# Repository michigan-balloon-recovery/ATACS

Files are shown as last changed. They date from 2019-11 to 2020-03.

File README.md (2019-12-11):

# ATACS
*the* Aerial Termination And Communication System

A global-range, two-way communication system for high-altitude balloons that enables reliable telemetry beaconing and on-demand flight termination.

## Subdirectories
* [Hardware](./hardware/README.md)
* Software
    * [Ground Station](./software/groundstation/README.md)
    * [RTOS](./software/rtos/README.md)

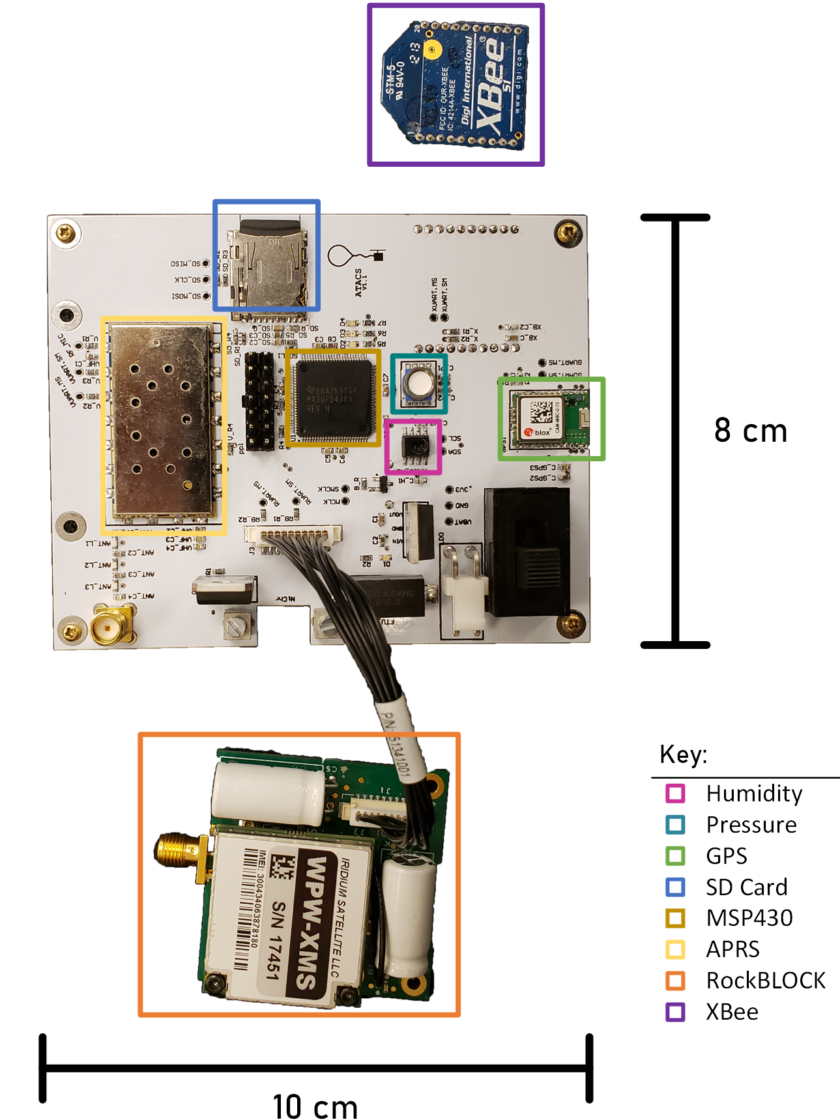
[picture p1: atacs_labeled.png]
Labeled PCB


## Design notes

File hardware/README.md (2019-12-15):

# ATACS hardware
Only tested in Altium 17, but should work in any version >=17. 

Simply open `board/ATACS.PrjPcb` in Altium and enjoy!

[Order a populated board on CircuitHub](https://circuithub.com/projects/MBuRST/ATACS/revisions/24389)

## Board Preview
**Top**

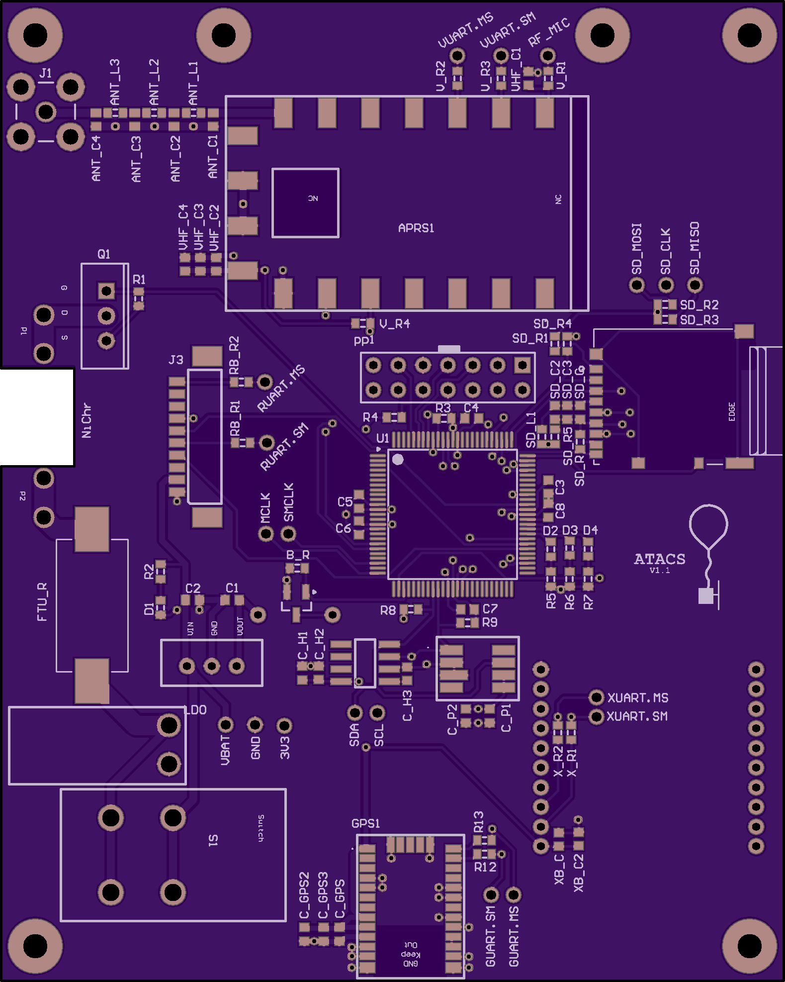
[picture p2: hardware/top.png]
Top


**Bottom**

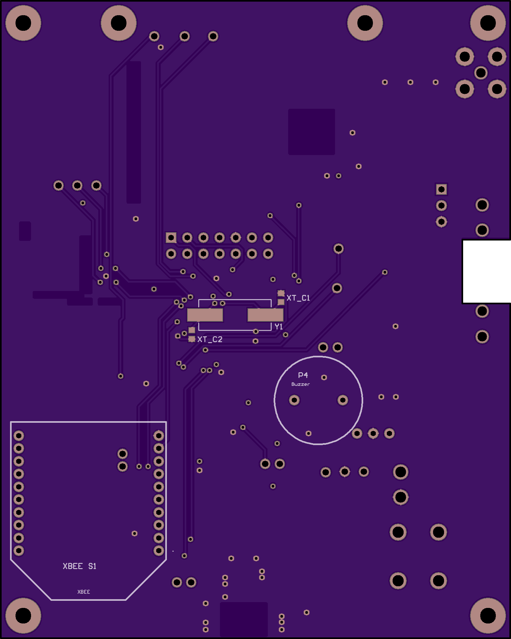
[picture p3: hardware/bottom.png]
Bottom


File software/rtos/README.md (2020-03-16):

# ATACS software
## Import instructions for Code Composer Studio 9
1. After installing CCS9, configure it to use a workspace that is **not** the same as the project directory.
2. `File` > `Import` > `Code Composer Studio` > `CCS Projects`
3. Set import source as `ATACS/software/rtos`, then Finish.

`rtos` should now appear in the Project Explorer pane

## Driver documentation
1. [APRS](./src/aprs/README.md)
2. [Buzzer](./src/buzzer/README.md)
3. [GNSS](./src/gnss/README.md)
4. [I2C](./src/I2C/README.md)
5. [Logging](./src/logging/README.md)
6. [Ring Buffer](./src/ring_buff/README.md)
7. [RockBLOCK](./src/RockBLOCK/README.md)
8. [Sensors](./src/Sensors/README.md)
9. [UART](./src/uart/README.md)
10. [XBee](./src/XBee/README.md)

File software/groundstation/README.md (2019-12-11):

# ATACS Ground Station software
## Dependencies
1. Windows Operating System
2. Python3 Installed
3. Firefox browser installed
4. Gmail account without duo authentication (RockBLOCK messages must be routed to this address on their control panel)
5. RockBLOCK account with credits available (to send messages)
6. Google Maps API key

## Usage
1. Download `groundstation.py`. Place it into a folder, it will generate a few files while running. Open the script in a text editor, we will have to change a few lines of the software.
2. Fill in your RockBLOCK username, password, and imei inside of the `rb_send_message()` function in the Python code.
3. Fill in your Google Maps API key inside of the `process_rb_message()` function in the Python code.
4. Make sure Firefox is installed and added to your enviornmental variables. This isn't difficult to do, try looking up how to do this for your operating system.
5. Open `groundstation.py` from terminal. Enter your email username and password. This must be the email that has RockBLOCK data being routed to it.
6. Press 'g' to get and decode the most recent packet from the RockBLOCK.
7. Press 's' to send a message to the RockBLOCK. Press 'f' afterward to cut the FTU. Sending commands to other payloads via 'p' is not yet implemented.
8. After 'q' to quit the program.
9. The program will loop forever until you quit.

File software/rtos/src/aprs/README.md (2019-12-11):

# APRS driver
[APRS (Automatic Packet Reporting System)](https://en.wikipedia.org/wiki/Automatic_Packet_Reporting_System) driver which uses Timer A1 to produce a PWM signal which, after being low-pass filtered, emulates the [AFSK](https://en.wikipedia.org/wiki/Frequency-shift_keying) tones expected by APRS. 

## Library Dependencies
1. FreeRTOS (semaphore and mutex support)
2. [Gustavo Litovsky's UART driver for MSP430](../uart/README.md) (modified to use [Frame-preserving ring buffer](../ring_buff/README.md))
3. [ATACS RockBLOCK](../RockBLOCK/README.md)
4. [ATACS GNSS](../gnss/README.md)
5. [ATACS Sensors](../Sensors/README.md)

## Hardware resources
* USCI A3
   * RX pin: P10.5
   * TT pin: P10.4

* Timer A1
   * CCR1 Output (TX): P2.2

* GPIO Pins
    * DRA818V PD pin:  P1.2
    * DRA818V PTT pin: P1.3

## Usage
* In `aprs.h`
    1. Set APRS source and destination callsigns. For most users, destination should remain as `APRS` and source should be the licensed operator's callsign.
    2. Set APRS comment (optional)
    3. Set APRS transmit period (should not be lower than `60000`)
    4. Set GPIO pins used by the RF module for PD (on/off) and PTT (push-to-talk, transmit enable)
    5. Set APRS transmit active level (active low or high)
* **ADVANCED USERS:** If you would like to modify beacon behavior, see the definition of `task_aprs` and `aprs_beacon` in `aprs.c`

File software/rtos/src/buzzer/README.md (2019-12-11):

# Buzzer Driver
Buzzer driver for:
1. Controlling when a buzzer is on or off. 

## Library Dependencies
1. FreeRTOS (timing support)

## Hardware Resources
1. GPIO Pin
   1. Buzzer Control Pin: P2.3

## Usage
1. Register `task_buzzer()` with the FreeRTOS kernel (ex. `xTaskCreate(task_buzzer, "buzzer", 128, NULL, 1, NULL);`).
2. Set the time the buzzer spends on in milliseconds by editing the `#define` in `buzzer.h` (ex. `#define BUZZ_ON_MS 1000`).
3. Set the timer the buzzer spends off in milliseconds by editing the `#define` in `buzzer.h` (ex. `#define BUZZ_OFF_MS 30000`).

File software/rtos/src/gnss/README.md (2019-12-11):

# GNSS Driver
GNSS (Global Navigation Satellite System) driver for:
1. generic modules through NMEA (`./NMEA.c`)
2. UBlox modules through UBX (not yet implemented)

## Library Dependencies
1. [FreeRTOS](https://www.freertos.org/index.html) (semaphore and mutex support)
2. [Gustavo Litovsky's UART driver for MSP430](../uart/README.md) (modified to use [Frame-preserving ring buffer](../ring_buff/README.md))

## Hardware Resources
1. USCI A0
   1. Tx pin: P3.4
   2. Rx pin: P3.5

## Usage
1. select between NMEA and UBX using the macro in `./GNSS.h` (i.e. `#define GNSS_NMEA` or `#define GNSS_UBX`)
2. set buffer lengths to desired sizes in `./GNSS.h`
3. add extra message decoders and get functions to `./NMEA.c` or `./UBX.c` if more data is necessary (such as expected error)
4. register `task_gnss()` with the FreeRTOS kernel (ex. `xTaskCreate(task_gnss, "gnss", 128, NULL, 1, NULL);`)
5. use get functions (`gnss_get_time()`, `gnss_get_location()`, `gnss_get_altitude()`, etc.) to retrieve GNSS data
6. use interrupt functions (`gnss_disable_interrupts()`, `gnss_enable_interrupts()`) to allow critical sections in other regions of code

## Adding NMEA Decoders
The NMEA decoding framework is designed to allow modular additions of sentence decoders depending on application. 
Refer to the NMEA spec or your GNSS module's datasheet to decide which sentences to decode.
1. **Add field decoder functions as necessary**: All NMEA sentences are encoded in ASCII so functions must be written to convert each field to a binary representation depending on what the contents of the field is. The function must follow this prototype: `static bool gnss_nmea_field_custom(uint8_t *start, uint8_t *end, void *data)` where `start` is a pointer to the beginning of the field and `end` is a pointer to the end of the field. `data` is a void pointer that can be used to return the decoded data.
2. **Add field decoder prototype**: add the function prototype for the field decoder in the *private prototypes* section at the top of `./NMEA.c`.
3. **decode all desired fields in the desired sentence case**: `gnss_nmea_decode_standard_msg()` and `gnss_nmea_decode_PUBX()` contain switch cases to sort the decoded sentences by ID. Add `gnss_nmea_decode_field()` calls with a function pointer to your custom field decoder to decode any desired fields in the case of the sentence you want to decode. The *GGA* example can be used as reference.
4. **store any new data in the GNSS global struct**: modify `./GNSS.h` to include your new data in the `gnss_t` type.
5. **implement get functions for any new data made available**: add custom get functions to `./GNSS.c` to retreive your new data. Ensure checks are made that the global struct has been initialized and the data mutex is available (ex. `gnss_obj->is_valid && xSemaphoreTake(gnss_obj->data_mutex, 100) == pdFALSE`).

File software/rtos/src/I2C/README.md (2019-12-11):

# I2C Driver
I2C (Inter-Integrated Circuits) driver for:
1. Sending messages from a microcontroller to I2C devices
2. Retrieving messages from I2C devices 

## Library Dependencies
1. [FreeRTOS](https://www.freertos.org/index.html) (semaphore and mutex support)

## Hardware Resources
1. USCI B0
   1. SDA: P3.1
   2. SCL: P3.2

## Usage
1. Set buffer lengths to desired sizes in i2c_driver.c
2. Use i2c_setup() to initialize I2C communication on UCB0
3. Use i2c_write() to send data from the microprocessor to an I2C device. 
4. Use i2c_read() to tell the microporccesor retrieve data from an I2C device. 
5. Use interrupt functions (i2c_enable_interrupts(), i2c_disable_interrupts()) to allow critical sections in other regions of code.

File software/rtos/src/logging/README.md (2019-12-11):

# Logging
Task for periodic logging and API for custom, event based logging.

## Library Dependencies
1. [FreeRTOS](https://www.freertos.org/index.html) (semaphore and mutex support)
2. [FatFs](http://elm-chan.org/fsw/ff/00index_e.html) fat32 file system
3. SPI driver from [Texas Instruments MSP430 MMC driver](http://www.ti.com/lit/an/slaa281c/slaa281c.pdf)

## Hardware Resources
1. USCI B3
   1. CS: P10.0
   2. SIMO: P10.1
   3. SOMI: P10.2
   4. CLK: P10.3
   
## Usage: Periodic Logging
1. Configure logging file sizes, period, etc in `./logging.h` **NOTE:** the most recent log will be unreadable if the logging is interrupted (device turned off, SD card removed) while writing. Size your logs small enough to avoid this.
2. Modify `log_init()` to start any custom logging sessions or change log file names/paths
3. Add any custom logging sessions to the `task_log()` function
   1. Call `log_resume_session()` before writing to the SD card
   2. Check that `log_resume_session()` returns true before writing anything to the file. This prevents two tasks from writing to the file at the same time and ensure the file is opened correctly.
   3. Write to the SD card using the file pointer returned by `log_resume_session()`
   4. Call `log_pause_session()` after the current entry has been written to the SD card
3. Register `task_log()` with the FreeRTOS kernel (ex. `xTaskCreate(task_log, "Logging", 512, NULL, 1, NULL);`)

## Usage: Event Based Logging
1. Configure logging file sizes, period, etc in `./logging.h` **NOTE:** the most recent log will be unreadable if the logging is interrupted (device turned off, SD card removed) while writing. Size your logs small enough to avoid this.
2. Modify `log_init()` to start any custom logging sessions or change log file names/paths
3. Create custom logging functions (ex. `log_gnss()`) for every device to log
   1. Call `log_resume_session()` before writing to the SD card
   2. Check that `log_resume_session()` returns true before writing anything to the file. This prevents two tasks from writing to the file at the same time and ensure the file is opened correctly.
   3. Write to the SD card using the file pointer returned by `log_resume_session()`
   4. Call `log_pause_session()` after the current entry has been written to the SD card
4. Call custom logging functions from any other FreeRTOS task. Logs are not synchronized with this method, so ensure to same timestamps or other contextual info.

## Log Format
The logging driver can theoretically be used to write in any format, but by default logs in Comma Seperated Value (CSV) format which can be read using Excel or Matlab.
Every file is writen with a custom header specified when the logging session is created with `log_start_session()`.
The logging driver will then allow `LOG_MAX_ENTRIES` to be written to a log file before incrementing the file name. 
The initial file name is specified when calling `log_start_session()` and must end in a numeric sequence with enough leading zeros to prevent increasing the string length.

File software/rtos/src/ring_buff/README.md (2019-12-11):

# Frame-preserving Ring Buffer
Ring buffer designed to prevent fragmented frames by independently storing byte and frame position.

## Library Dependencies
None

## Hardware Resources
None

## Usage
## Initialization
1. Create a global-scope array of type `uint8_t` or equivalent
2. Call `ring_buff_init()` and pass in a empty `ring_buff_t` instance and the byte array to use.

## Write to Buffer
1. Call `ring_buff_write_clear_packet()` at the beginning of a frame to clear out any partial frames
2. Call `ring_buff_write()` to add each byte of the frame
3. Call `ring_buff_write_finish_packet()` to mark the packet as finished. **Warning:** If the frame isn't marked as finished, it will be deleted when `ring_buff_write_clear_packet()` is called.

## Read from Buffer
1. Call `ring_buff_read_clear_packet()` at the beginning of a read to ensure the pointer is at the start of a frame
2. Call `ring_buff_read()` to read in each byte of the frame
3. Call `ring_buff_read_finish_packet()` when the End-Of-Frame (EOF) is detected to mark the frame as read. **Warning:** If the frame isn't marked as finished, the buffer will be unable to use the memory occupied by the current frame.

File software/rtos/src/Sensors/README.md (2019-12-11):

# Sensor Driver
Sensor driver for:
1. Calculating and retrieving pressure, humidity, and temperature data

## Library Dependencies
1. [FreeRTOS](https://www.freertos.org/index.html) (semaphore and mutex support)
2. [i2c driver](../I2C/README.md) 

## Hardware Resources
1. USCI B0
   1. SDA pin: P3.1
   2. SCL pin: P3.2

## Usage
1. Register task_humidity and task_pressure with the FreeRTOS kernel.
   (ex. `xTaskCreate(task_pressure, "pressure", 1024,NULL,1,NULL);`)
2. Use `sens_init_pressure()` to initialize the pressure sensor and read in its calibration values. 
   There is no initialization necessary for the humidity sensor.
3. Use `sens_calc_pressure()` to initialize a new pressure and temperature reading from the pressure sensor.
4. Use `sens_calc_humidity()` to initialize a new humidity and temperature reading from the humidity sensor.
5. Use `sens_get_pres()` to retrieve the current pressure reading.
6. Use `sens_get_ptemp()` to retrieve the current temperature reading from the pressure sensor.
7. Use `sens_get_humid()` to retrieve the current humidity reading.
8. Use `sens_get_htemp()` to retriece the current temperature reading from the humidity sensor.
9. Use functions (`sens_disable_interrupts()`, `sens_enable_interrupts()`) to safely allow for critical sections in other regions of code.

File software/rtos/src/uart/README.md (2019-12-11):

# UART Driver
Genaric UART driver for the MSP430 by Gustavo Litovsky (Refer to copywrite notice in `./uart.c`).
Has been heavily modified to support Paul Young's [Frame-preserving ring buffer](../ring_buff/README.md) as well as adding callback functions for RX and TX operations.

## Library Dependencies
1. Gustavo Litovsky's [original MSP430 UART driver](https://github.com/glitovsky38412/msp430uartdriver)
2. Paul Young's [Frame-preserving ring buffer](../ring_buff/README.md)

## Hardware Resources
configured by application drivers

## Usage

## Initialization
1. Create and initialize a `UARTConfig` struct, filling in *moduleName*, *PortNum*, *RxPinNum*, *TxPinNum*, *clkRate*, *baudRate*, *clkSrc*, *databits*, *parity*, and *stopbits* based on the application
2. Call `initUSCIUart()`, passing in the `UARTConfig` struct and any ring buffers being used. If a ring buffer isn't being used due to callback functions, a NULL pointer can be passed in instead.
3. Call `initUartRxCallback()` and/or `initUartTxCallback()` to initialize callback functions
   1. A function pointer to a callback of prototype `void callback_fcn(void *param, uint8_t datum)` should be passed in
   2. data can be returned from the callback function using the void pointer *params* that will be passed into the callback function

## RX
After initialization, the RX interrupt is automatically enabled. When the interrupt is triggered, the callback function will be called, if initialized. 
If no callback is defined, the interrupt will load the byte into the ring buffer and finish the frame.
If no callback or ring buffer is defined, nothing will happen.

## TX: Blocking
A byte array can be transmitted over UART without interrupts by using `uartSendDataBlocking()`. This will lock up the current task until the transmission is completed.
No callbacks or internal buffers are used for this transmission method.

## TX: Interrupts
Interrupts can be used to free the task for other operations while transmission is occuring. The driver supports callback functions and a Frame-preserving ring buffer.
1. Start the transmission using `uartSendDataInt()`. This enables TX interrupts and triggers the first interrupt with software.
2. After each byte is transmitted, an interrupt is triggered which calls the callback function, if defined.
3. If no callback function is defined, a single byte is read from the ring buffer (and transmitted) and the frame is marked as complete.
4. If no callback or ring buffer is defined, nothing will happen

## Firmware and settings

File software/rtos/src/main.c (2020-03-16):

/* Standard includes. */
#include <MSP430-5438STK_HAL/hal_MSP430-5438STK.h>
#include <stdio.h>
/* FreeRTOS includes. */
#include "FreeRTOS.h"
#include "task.h"
#include "semphr.h"

/* Hardware includes. */
#include "driverlib.h"
#include "uart.h"
#include "gnss.h"
#include "aprs.h"
#include "rockblock.h"
#include "sensors.h"
#include "i2c_driver.h"
#include "logging.h"
#include "buzzer.h"

/*-----------------------------------------------------------*/

static void prvSetupHardware(void);

/*-----------------------------------------------------------*/

void main( void ) {
    /* Initialize Hardware */
    prvSetupHardware();

    /* Create Tasks */
    xTaskCreate((TaskFunction_t) task_gnss,           "gnss",             128, NULL, 1, NULL);
    xTaskCreate((TaskFunction_t) task_aprs,           "aprs",             512, NULL, 1, NULL);
    xTaskCreate((TaskFunction_t) task_pressure,       "pressure",         128, NULL, 1, NULL);
    xTaskCreate((TaskFunction_t) task_humidity,       "humidity",         128, NULL, 1, NULL);
    xTaskCreate((TaskFunction_t) task_buzzer,         "buzzer",           128, NULL, 1, NULL);
    xTaskCreate((TaskFunction_t) task_rockblock,      "RockBLOCK",        512, NULL, 1, NULL);
    xTaskCreate((TaskFunction_t) task_log,            "Logging",          512, NULL, 1, NULL);


    /* Start the scheduler. */
    __bis_SR_register(GIE); // Global interrupt enable
    vTaskStartScheduler();

    /* If all is well then this line will never be reached.  If it is reached
    then it is likely that there was insufficient (FreeRTOS) heap memory space
    to create the idle task.  This may have been trapped by the malloc() failed
    hook function, if one is configured. */
    for( ;; );
}

/*-----------------------------------------------------------*/

static void prvSetupHardware(void) {
	taskDISABLE_INTERRUPTS();
	
	/* Disable the watchdog. */
	WDTCTL = WDTPW + WDTHOLD;

	/* Set DCO to 16MHz, uses configCPU_CLOCK_HZ, but PMM_CORE_LEVEL_x is hardcoded */
	GPIO_setAsPeripheralModuleFunctionOutputPin(GPIO_PORT_P1, GPIO_PIN6);
	GPIO_setAsPeripheralModuleFunctionOutputPin(GPIO_PORT_P2, GPIO_PIN0);

	//Set VCore = 2 for 16MHz clock
    PMM_setVCore(PMM_CORE_LEVEL_2);

    //Set DCO FLL reference = REFO
    UCS_initClockSignal(
        UCS_FLLREF,
        UCS_REFOCLK_SELECT,
        UCS_CLOCK_DIVIDER_1
        );

    UCS_initFLLSettle(
            configCPU_CLOCK_HZ / 1000,
            configCPU_CLOCK_HZ / 32768
    );

    halBoardInit();

    /* debug LEDs */
    GPIO_setAsOutputPin(GPIO_PORT_P8, GPIO_PIN2);
    GPIO_setAsOutputPin(GPIO_PORT_P8, GPIO_PIN3);
    GPIO_setAsOutputPin(GPIO_PORT_P8, GPIO_PIN4);
    GPIO_setOutputLowOnPin(GPIO_PORT_P8, GPIO_PIN2);
    GPIO_setOutputLowOnPin(GPIO_PORT_P8, GPIO_PIN3);
    GPIO_setOutputLowOnPin(GPIO_PORT_P8, GPIO_PIN4);

    /* UART */
    initUartDriver();

    /* I2C */
    i2c_setup();


}
/*-----------------------------------------------------------*/


void vApplicationTickHook(void) {
	return;
}

/*-----------------------------------------------------------*/

/* The MSP430X port uses this callback function to configure its tick interrupt.
This allows the application to choose the tick interrupt source.
configTICK_VECTOR must also be set in FreeRTOSConfig.h to the correct
interrupt vector for the chosen tick interrupt source.  This implementation of
vApplicationSetupTimerInterrupt() generates the tick from timer A0, so in this
case configTICK_VECTOR is set to TIMER0_A0_VECTOR. */
void vApplicationSetupTimerInterrupt(void) {
    const unsigned short usACLK_Frequency_Hz = 32768;

	/* Ensure the timer is stopped. */
	TA0CTL = 0;

	/* Run the timer from the ACLK. */
	TA0CTL = TASSEL_1;

	/* Clear everything to start with. */
	TA0CTL |= TACLR;

	/* Set the compare match value according to the tick rate we want. */
	TA0CCR0 = usACLK_Frequency_Hz / configTICK_RATE_HZ;

	/* Enable the interrupts. */
	TA0CCTL0 = CCIE;

	/* Start up clean. */
	TA0CTL |= TACLR;

	/* Up mode. */
	TA0CTL |= MC_1;
}
/*-----------------------------------------------------------*/

void vApplicationIdleHook(void) {
	/* Called on each iteration of the idle task.  In this case the idle task
	just enters a low(ish) power mode. */
//	__bis_SR_register( LPM1_bits + GIE );
}
/*-----------------------------------------------------------*/

void vApplicationMallocFailedHook(void) {
	/* Called if a call to pvPortMalloc() fails because there is insufficient
	free memory available in the FreeRTOS heap.  pvPortMalloc() is called
	internally by FreeRTOS API functions that create tasks, queues or
	semaphores. */
	taskDISABLE_INTERRUPTS();
	for( ;; );
}
/*-----------------------------------------------------------*/

void vApplicationStackOverflowHook(TaskHandle_t pxTask, char *pcTaskName) {
	( void ) pxTask;
	( void ) pcTaskName;

	/* Run time stack overflow checking is performed if
	configconfigCHECK_FOR_STACK_OVERFLOW is defined to 1 or 2.  This hook
	function is called if a stack overflow is detected. */
	taskDISABLE_INTERRUPTS();
	for( ;; );
}
/*-----------------------------------------------------------*/

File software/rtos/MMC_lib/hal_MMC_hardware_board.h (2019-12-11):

//----------------------------------------------------------------------------
//  This include file contains definitions specific to the hardware board.
//----------------------------------------------------------------------------
// ********************************************************

//----------------------------------------------------------------------------
// SPI/UART port selections.  Select which port will be used for the interface 
//----------------------------------------------------------------------------
#define SPI_SER_INTF      SER_INTF_USCIB3  // Interface to MMC

#include <msp430.h>

// SPI port definitions
#define SPI_PxSEL         P10SEL
#define SPI_PxDIR         P10DIR
#define SPI_PxIN          P10IN
#define SPI_PxOUT         P10OUT
#define SPI_SIMO          0x02
#define SPI_SOMI          0x04
#define SPI_UCLK          0x08


// SPI port definitions
#define MMC_PxSEL         SPI_PxSEL
#define MMC_PxDIR         SPI_PxDIR
#define MMC_PxIN          SPI_PxIN
#define MMC_PxOUT         SPI_PxOUT
#define MMC_SIMO          SPI_SIMO
#define MMC_SOMI          SPI_SOMI
#define MMC_UCLK          SPI_UCLK

// Chip Select
#define MMC_CS_PxOUT      P10OUT
#define MMC_CS_PxDIR      P10DIR
#define MMC_CS            0x01

#define CS_LOW()    MMC_CS_PxOUT &= ~MMC_CS               // Card Select
#define CS_HIGH()   while(halSPITXDONE); MMC_CS_PxOUT |= MMC_CS  // Card Deselect

#define DUMMY_CHAR 0xFF

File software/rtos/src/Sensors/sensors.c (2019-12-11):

#include "sensors.h"
#include <driverlib.h>

/**
 * sensors.c
 */

sensor_data_t sensor_data = {.humid_init = false, .pres_init = false};

void task_pressure(void) {
//    const portTickType xFrequency = 1000 / portTICK_RATE_MS;

    sensor_data.pressureSemaphore = xSemaphoreCreateMutex();
    sens_init_pres();

    int32_t data[2] = {0, 0};
    bool pres_valid = false;

    while(1) {

        if(sens_calc_pres(data))
            pres_valid = true;
        else
            pres_valid = false;

        if(xSemaphoreTake(sensor_data.pressureSemaphore,100/portTICK_RATE_MS) == pdTRUE) {
            sensor_data.pressure = data[0];
            sensor_data.pTemp = data[1];
            sensor_data.pres_valid = pres_valid;
            xSemaphoreGive(sensor_data.pressureSemaphore);
        }
        vTaskDelay(1000 / portTICK_RATE_MS);
    }
}

void task_humidity(void) {
    const portTickType xFrequency = 1000 / portTICK_RATE_MS;

    sensor_data.humiditySemaphore = xSemaphoreCreateMutex();
    sensor_data.humid_init = true;
    int32_t data[2] = {0, 0};
    bool humid_valid = false;

    while(1) {
        //GPIO_setOutputHighOnPin(GPIO_PORT_P8, GPIO_PIN3);

        if(sens_calc_humid(data))
            humid_valid = true;
        else
            humid_valid = false;

        if(xSemaphoreTake(sensor_data.humiditySemaphore, 100/portTICK_RATE_MS) == pdTRUE) {
            sensor_data.humidity = data[0];
            sensor_data.hTemp = data[1];
            sensor_data.humid_valid = humid_valid;
            xSemaphoreGive(sensor_data.humiditySemaphore);
        }

        //GPIO_setOutputLowOnPin(GPIO_PORT_P8, GPIO_PIN3);
        vTaskDelay(xFrequency);
    }
}
 
void sens_init_pres(void) {
	uint8_t cmd[1];
	
    unsigned int j;
    volatile unsigned int i;
    for(i = 0; i < 8; i++)
        c[i] = 0;

	cmd[0] = 0x1E;
    while(i2c_write(0x77, cmd, 1) == false);
    for(j = 0; j<8; j++) {
        uint8_t data[2];
        vTaskDelay(100/portTICK_PERIOD_MS);
        cmd[0] = 0xA0 + j*2;
        while(i2c_write(0x77, cmd, 1) == false);
        vTaskDelay(100/portTICK_PERIOD_MS);
        while(i2c_read(0x77, data, 2) == false);
        c[j] = data[0];
        c[j] = c[j] << 8;
        c[j] += data[1];
    }
    sensor_data.pres_init = true;
}

void sens_enable_interrupts(void) {

    i2c_enable_interrupts();
    return;

}

bool sens_disable_interrupts(void) {

    return i2c_disable_interrupts();

}
 
bool sens_calc_pres(int32_t* return_data) {
    uint8_t data[4] = {0x0, 0x0, 0x0, 0x0};
    uint8_t cmd[1];

    int64_t pressure = 0;

    uint32_t d1, d2;

    int64_t dT, pTemp;
    int64_t offset, sens;

    //retrieves digital pressure value
    vTaskDelay(100/portTICK_PERIOD_MS);
    cmd[0] = 0x48;

    if(i2c_write(0x77, cmd, 1) == false)
        return false;

    vTaskDelay(100/portTICK_PERIOD_MS);
    cmd[0] = 0x00;

    if(i2c_write(0x77, cmd, 1) == false)
        return false;


    vTaskDelay(100/portTICK_PERIOD_MS);

    if(i2c_read(0x77, data, 3) == false)
        return false;


    d1 = data[0];
    d1 = d1 << 8;
    d1 += data[1];
    d1 = d1 << 8;
    d1 += data[2];

    //retrieves digital temperature value
    cmd[0] = 0x58;

    if(i2c_write(0x77, cmd, 1) == false)
        return false;

    vTaskDelay(100/portTICK_PERIOD_MS);
    cmd[0] = 0x00;
    if(i2c_write(0x77, cmd, 1) == false)
        return false;

    vTaskDelay(100/portTICK_PERIOD_MS);

    if(i2c_read(0x77, data, 3) == false)
        return false;

    d2 = data[0];
    d2 = d2 << 8;
    d2 += data[1];
    d2 = d2 << 8;
    d2 += data[2];

    //calculate temperature
    dT = c[5];
    dT = dT << 8;
    dT = d2 - dT;

    pTemp = c[6];
    pTemp *= dT;
    pTemp = pTemp >> 23;
    pTemp += 2000;

    //calculate temperature compensated pressure
    int64_t temporary;
    offset = c[2];
    offset = offset << 16;
    temporary = c[4];
    temporary *= dT;
    temporary = temporary >> 7;
    offset = offset + temporary;

    sens = c[1];
    sens = sens << 15;
    temporary = c[3];
    temporary *= dT;
    temporary = temporary >> 8;
    sens = sens + temporary;

    pressure = d1;
    pressure *= sens;
    pressure = pressure >> 21;
    pressure -= offset;
    pressure = pressure >> 15; // 32768
    pressure /= 100;

    pTemp += 50;
    pTemp /= 100;

    return_data[0] = pressure;
    return_data[1] = pTemp;
    return true;
}

bool sens_calc_humid(int32_t *return_data) {
    uint32_t hum = 0;
    uint8_t data[4] = {0x0, 0x0, 0x0, 0x0};
    int32_t temp = 0;

    if(i2c_write(0x27, 0, 0) == false)
        return false;

    vTaskDelay(50/portTICK_PERIOD_MS);

    if(i2c_read(0x27, data, 4) == false)
        return false;

    hum = data[0] & 0x3F;
    hum = hum << 8;
    hum += data[1];
    hum = 100*hum;
    //hum += 8191; // add 1/2 LSB for accurate rounding
    hum = hum/16382;
    temp = data[2];
    temp = temp << 6;
    temp += (data[3] >> 2);
    temp = 165*temp;
    //temp += 8191; // add 1/2 LSB for accurate rounding
    temp = temp / 16382;
    temp -= 40;

    return_data[0] = hum;
    return_data[1] = temp;
    return true;
}

bool sens_get_pres(int32_t* pressure) {
	if(!sensor_data.pres_init || xSemaphoreTake(sensor_data.pressureSemaphore,100) == pdFALSE)
		return false;

	*pressure = sensor_data.pressure;
	bool toReturn = sensor_data.pres_valid;
    xSemaphoreGive(sensor_data.pressureSemaphore);
    return toReturn;
}

bool sens_get_ptemp(int32_t* temp) {
	if(!sensor_data.pres_init || xSemaphoreTake(sensor_data.pressureSemaphore,100) == pdFALSE)
	    return false;

	*temp = sensor_data.pTemp;
	bool toReturn = sensor_data.pres_valid;
    xSemaphoreGive(sensor_data.pressureSemaphore);
    return toReturn;
}

bool sens_get_humid(int32_t* humidity) {
	if(!sensor_data.humid_init || xSemaphoreTake(sensor_data.humiditySemaphore, 100) == pdFALSE)
	    return false;

    *humidity = sensor_data.humidity;
    bool toReturn = sensor_data.humid_valid;
    xSemaphoreGive(sensor_data.humiditySemaphore);
    return toReturn;
}


bool sens_get_htemp(int32_t* temp) {
    if(!sensor_data.humid_init || xSemaphoreTake(sensor_data.humiditySemaphore, 100) == pdFALSE)
        return false;

    *temp = sensor_data.hTemp;
    bool toReturn = sensor_data.humid_valid;
    xSemaphoreGive(sensor_data.humiditySemaphore);
    return toReturn;
}

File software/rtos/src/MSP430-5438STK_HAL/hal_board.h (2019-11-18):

/**********************************************************************//**
    Filename: hal_board.h

    Copyright 2010 Texas Instruments, Inc.
***************************************************************************/
#ifndef HAL_BOARD_H
#define HAL_BOARD_H

#define LED_PORT_DIR      P10DIR
#define LED_PORT_OUT      P10OUT
#define LED_1             BIT7
#define LED_2             BIT6

#define CLK_PORT_DIR      P11DIR //outputs clocks to testpoints
#define CLK_PORT_OUT      P11OUT
#define CLK_PORT_SEL      P11SEL

/*----------------------------------------------------------------
 *                  Function Prototypes
 *----------------------------------------------------------------
 */
static void halBoardGetSystemClockSettings(unsigned char systemClockSpeed, 
                                           unsigned char *setDcoRange,
                                           unsigned char *setVCore,
                                           unsigned int  *setMultiplier);

extern void halBoardOutputSystemClock(void);
extern void halBoardStopOutputSystemClock(void);
extern void halBoardInit(void);
void hal430SetSystemClock(unsigned long req_clock_rate, unsigned long ref_clock_rate);

#endif /* HAL_BOARD_H */

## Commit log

2019-10-17 MSP430 driverlib now included in project, started header for rockblock driver
2019-10-17 Driverlib properly included in project now
2019-10-19 driverlib back
2019-10-19 hardware dir restructure. Also some project compiler issues addressed
    [ADCSComponents.SchLib, ADCSFootprints.PcbLib, ATACS.PrjPcb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]
2019-10-19 Updated gitignore and converted schematics to ASCII
    [ATACS_SCH.SchDoc, EPS_SCH.SchDoc, MSP430F5438A.SchDoc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]
2019-10-19 hardware dir restructure again
    [ATACS.PrjPcb, ATACS_SCH.SchDoc, EPS_SCH.SchDoc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]
2019-10-19 added driverlib docs and examples
2019-10-21 top-level schematic connected, basic ftu added, jtag/debug connector added
    [ATACS.PrjPcb, ATACS_SCH.SchDoc, EPS_SCH.SchDoc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]
2019-10-24 LPF added to VHF module
    [ATACS_SCH.SchDoc, MSP430F5438A.SchDoc, TELEMETRY_SCH.SchDoc]
2019-10-29 need to remove buildfiles
    [GenQTest.obj, HAL_PMM.obj, ParTest.obj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]
2019-10-29 buildfiles removed
    [GenQTest.obj, RegTest.obj, TimerDemo.obj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]
2019-10-30 Fixed SD Card schematic, added SD card footprint.
    Still need to do SMA connector from APRS transmitter, JTAG connectors, and FTU footprints.
    Where is the switch from? I can't find it anywhere :(
    [ATACS_PCB.PcbLib, ATACS_SCH.SchDoc, EPS_SCH.SchDoc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]
2019-11-01 basic LED + UART tasks working
2019-11-01 refactor UART initialization, transmit and loopback tests successful
2019-11-01 added driverlib with basic tone generation
2019-11-04 made some ground routes better, via sizes uniform
    [ATACS_PCB.PcbDoc]
2019-11-06 version of board sent to fab for v1
    [ATACS.PrjPcb, ATACS_PCB.PcbDoc, ATACS_SCH.SchDoc]
2019-11-06 modified uart driver to support GNSS driver
2019-11-06 board update
    [ATACS.PrjPcb, ATACS_PCB.PcbDoc, ATACS_PCB.PcbLib]
2019-11-06 resolved merge issues between afsk and gnss
    [afsk.c, afsk.h, main.c]
2019-11-08 updated uart driver to use ring buffers and added RX callback functions
2019-11-09 added tx callback to uart driver
2019-11-09 commented custom uart functions and ring buff functions
2019-11-10 wrote rockblock driver. Need to test
2019-11-12 basic APRS beacon working. need to add digipeater path and collect actual data from sensors
2019-11-15 Uploaded the I2C files
2019-11-17 sensor functions
2019-11-19 get sensor data functions
2019-11-19 sensor data get functions
2019-11-19 change sensor semaphore implementation
2019-11-19 fixed sensors.h and c with naming issues and main fixed truncation for rockblock
    [main.c, sensors.c]
2019-11-19 added SD card driver and FATfs middleware
2019-11-19 fixed sign issue for gnss_coord_to_dec
    [gnss.c]
2019-11-19 fixed sensors to modify pointers correctly
    [sensors.c]
2019-11-19 created telemetry packet function, untested currently
2019-11-19 fixed rockblock bugs and function def for conversion function
    [rockblock.c]
2019-11-20 fixed SD card SPI and started debugging FATfs
    [hal_MMC_hardware_board.h, hal_SPI.c, hal_SPI.h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]
2019-11-21 HAL, APRS changes to reflect actual board hardware
2019-11-21 cleaned up aprs library, need to add UART for DRA818V config
2019-11-21 fixed build, cleaning up i2c
    [i2c_driver.c, main.c]
2019-11-21 cleaned up i2c, sensors code
2019-11-21 changed SD spi to UCB3
2019-11-21 uart header updated to reflect P10's existence on F5438A
2019-11-21 sensors cleaned
2019-11-21 did some things to make i2c work
2019-11-22 switched from freeRTOS + FAT to FATfs file system
    [mkfs.xlsx]
2019-11-22 fixed some dependencies from freeRTOS + FAT
    [main.c]
2019-11-23 fixed logging compiling issue
    [logging.c]
2019-11-23 fixed a bunch of warnings
    [logging.c, main.c, nmea.c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]
2019-11-23 fixed pass by pointer get functions
    [logging.c, sensors.c]
2019-11-23 fixed i2C and more
    [gnss.c, i2c_driver.c, logging.c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]
2019-11-24 tested pressure sensor
2019-11-24 fixxed small bug on retrieving ascii
    [rockblock.c]
2019-11-26 pcb rev 2
    [ATACS.PrjPcb, ATACS_PCB.PcbDoc, ATACS_PCB.PcbLib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]
2019-11-26 updated SD card driver to support SDHC
2019-11-27 edits per allpcb's comments
    [ATACS.PrjPcb, ATACS_PCB.PcbDoc]
2019-11-28 uart driver now supports usci_a3
2019-11-28 APRS beacon now works if it is the only task running (no other interrupts enabled)... Need to figure out how to disable all other interrupts while transmitting then re-enable them.
2019-11-28 Added condition to get functions to prevent hanging if they are called before gnss_obj->data_mutex is created
    [gnss.c]
2019-11-28 prevent sensor get functions from hanging if called before mutex created
    [sensors.c]
2019-11-28 fixed log file length
    [logging.c, sd_disk.c]
2019-11-28 fixed merge I screwed up
    [main.c]
2019-11-30 fixed SD card driver (with SDHC support)
    [logging.c, sd_disk.c]
2019-12-02 added log file headers, added re-entrency to FATfs, and added interrupt enable/disable functions for GNSS
2019-12-02 fixed sensor tasks' array size
    [sensors.c]
2019-12-02 almost have rockblock disabling working. Currently is safe, need to actually disable uart somehow?
2019-12-02 i2c is safer and has enable/disable interrupts functions
2019-12-03 uart interrupt disable function added to library
2019-12-03 vhf config uart disable to use library function
2019-12-03 better function prototypes for rb interrupts
2019-12-03 uart disable fixed and aprs now disables all interrupt sources other than timer used for pwm
    [aprs.c, uart.c]
2019-12-03 rockblock actually disables interrupts now
2019-12-03 bug fix for enable interrupts
    [rockblock.c]
2019-12-03 removed lpm0 from i2c cuz no reason for it
2019-12-03 i2c fixed?
2019-12-03 pressure actually works for real this time. thanks scott yay i wanna not work anymore plz send help
    [i2c_driver.c, main.c, sensors.c]
2019-12-03 i2c fixed for humidity sensor
    [i2c_driver.c, main.c]
2019-12-04 fixed I2C again
2019-12-04 increased number of samples per log file
2019-12-04 fixed FTU critical sections
    [rockblock.c]
2019-12-04 added change baud rate functionality to SPI driver
2019-12-05 fixed AT+SBDWT bug maybe
    [rockblock.c]
2019-12-05 prescaler=0 was causing issues we think
    [logging.c]
2019-12-05 try this for i2c
2019-12-05 switched GNSS coordinates to being stored as decMilliSec
2019-12-05 I entirely rewrote i2c
2019-12-05 whoops i2c read has stuf
2019-12-05 working toward i2c working
2019-12-05 i2c moved
2019-12-05 latest version of rewritten driver, maybe broken
    [i2c_driver.c]
2019-12-05 OK REVERTING TO OLD DRIVER THIS LOOKS LIKE IT WORKS
    [i2c_driver.c]
2019-12-05 fixed FIR shift order
    [nmea.c]
2019-12-05 im afraid sens_disable_interrupts is breaking our i2c driver
2019-12-05 need to make led an output
2019-12-05 LED at P8.4 now indicates GPS lock
2019-12-05 all tasks other than BUZZER
    [main.c]
2019-12-05 fixed GNSS millisecond multiplication error
    [nmea.c]
2019-12-05 added led to ftu, removed from humidity. maybe ftu will work now
2019-12-05 gnss compatability with aprs and gps led
2019-12-06 increased period of buzzer and rockblock transmissions
    [main.c, rockblock.c]
2019-12-07 commented GNSS, NMEA, ring buffer, and logging drivers
2019-12-07 added links to driver readme files
2019-12-10 commenting i2c
2019-12-10 sensor read me file
2019-12-10 Begin i2c read me
2019-12-10 fix i2c read me link
2019-12-10 added UART readme
2019-12-10 added link to original UART driver
2019-12-10 fixed sensors readme link
2019-12-11 added groundstation files
